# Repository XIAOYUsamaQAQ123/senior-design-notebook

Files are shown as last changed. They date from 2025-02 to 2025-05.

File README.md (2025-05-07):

# Senior Design Notebook

This repository serves as a **digital lab notebook** for Liangcheng's Senior Design project.

## 📂 Structure
- **docs/** → Project documentation
- **experiments/** → Experimental results.
- **src/** → Source code for the project.
- **hardware/** → PCB designs, schematics, and CAD files.
- **reports/** → Proposal, presentation, and final reports.

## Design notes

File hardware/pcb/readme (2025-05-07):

# PCB Designs

This folder contains all the PCB design files used throughout our project. 
It includes schematics, layout files, and fabrication outputs for each board revision.

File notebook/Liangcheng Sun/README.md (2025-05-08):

# Liangcheng Sun’s Worklog

Here is Liangcheng Sun’s worklog.

---
- [**2025-02-12 – Project design & proposal**] 
  I am drawing the full block diagram for our system and then writing up the project proposal so we have a clear plan.
  [Block Diagram](./block_diagram.pdf)
  [PCB Schematic](./main_control_board_schematic.pdf)
  [PCB Design](./main_control_board.pdf)

- [**2025-02-21 – Hardware components ordered online**]
  Based on our design, I went online to order all the needed parts, and I made sure each piece matches our specs.
  Order

- [**2025-02-25 – PCB design kickoff**] 
  After a quick study of PCB layout rules, I began designing our board, placing components and routing tracks step by step.

- [**2025-03-02 – OLED troubleshooting on breadboard**]  
  I built the main circuit on a breadboard, but the OLED display stayed blank—so I measured every pin voltage on both the ESP32 and the OLED, and all readings looked normal.
  OLED Screen:
  ESP32 Wroom 32:

- [**2025-03-06 – Swapped ESP32 for ATmega328**]  
  To isolate the issue, I replaced the ESP32 with an ATmega328, but despite the swap, the screen still would not turn on.
  Arduino nano board ATmega328:

- [**2025-03-12 – Demo & TA feedback (moved to ML training)**]
  During our breadboard demo, we showed partial functions and explained the OLED issue to TA Maanas and Professor—then they suggested skipping the OLED for now and focusing on ML model training and the camera interface.

- [**2025-03-23 – OLED still failing after hardware swap**]
  Even after replacing all hardware modules and checking connections again, the OLED remains unresponsive, so I need another plan.

- [**2025-04-15 – Raspberry Pi camera setup & capture via SSH**] 
  I successfully set up the Raspberry Pi camera, and now I can control it from my laptop via SSH to capture images automatically.
  Raspberry Pi 4: 
  Camera Module:

- [**2025-04-23 – Redesign: ATmega328 + remote display + nRF24L01**]
  We redesigned our system: kept the ATmega328, removed the OLED in favor of a screen on a remote device, and added two nRF24L01 modules so the Pi and ATmega can talk wirelessly; I then laid out and ordered a new PCB.
  [New Block Diagram](./final_block_diagram.pdf)
  [New PCB Schematic](./alert_system_board_schematic.pdf)
  [New PCB Design](./alert_system_board.pdf)
  nRF24L01:

- [**2025-04-26 – Swapped Pi camera for webcam**(./2025-04-26.md)  
  To improve reliability, I replaced the Pi camera module with a standard USB webcam that works smoothly.

- [**2025-04-27 – nRF24L01 issues → fallback to USB cable**]
  After facing unreliable links with the nRF24L01 modules, I decided to use a USB cable to connect the Pi and ATmega directly, which is more stable.

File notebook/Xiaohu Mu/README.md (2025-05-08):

# Xiaohu Worklog 
- [Xiaohu Worklog](#Xiaohu-worklog)
- [2025-02-17-Discussion with Professor Fliflet](##2025-02-17-Discussion-with-Professor-Fliflet)
- [2025-02-27-PCB Update](##2025-02-27-PCB-Update)
- [2025-03-03-Initial Design on Breadboard](#2025-03-03-Initial-Design-on-Breadboard)
- [2025-03-17-Working on the YOLOV5 model](#2025-03-17-Working-on-the-YOLOV5-model)
- [2025-04-21-Working on the UI and ssh connection to laptop](#2025-04-21-Working-on-the-UI-and-ssh-connection-to-laptop)
- [2025-04-27-Trasplanting the model from laptop to Raspberry Pi](#2025-04-27-Trasplanting-the-model-from-laptop-to-Raspberry-Pi)
---
## 2025-02-17-Discussion with Professor Fliflet
During the proposal review, Professor Fliflet provided suggestions for implementing the ideas we outlined. We decided to use the YOLOv5 model as our baseline to recognize and classify tools across various categories. We plan to train the model on our laptop before deploying it to a Raspberry Pi. Additionally, we will use an LCD screen to display item statuses on both the bench and in the drawer.
## 2025-02-27-PCB Update
We came up with an initial PCB design that includes the STM32 microcontroller, an LED, and a buzzer.
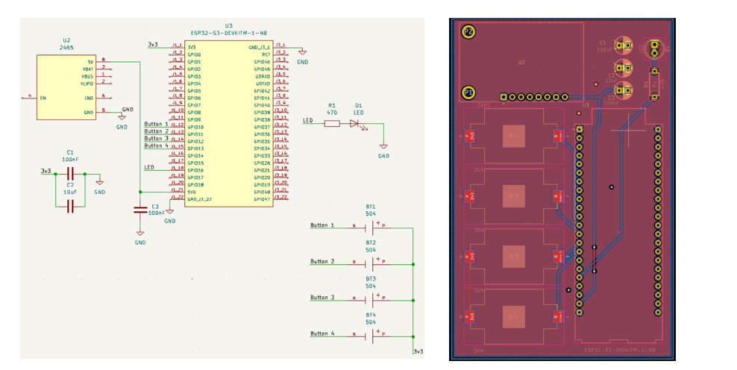
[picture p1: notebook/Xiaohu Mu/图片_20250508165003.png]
PCB Initial Design

## 2025-03-03-Initial Design on Breadboard
For our breadboard demonstration, we attempted to connect the LCD screen to the STM32 microcontroller, but it did not function as expected. Additionally, the STM32 failed to transmit data reliably to the laptop.
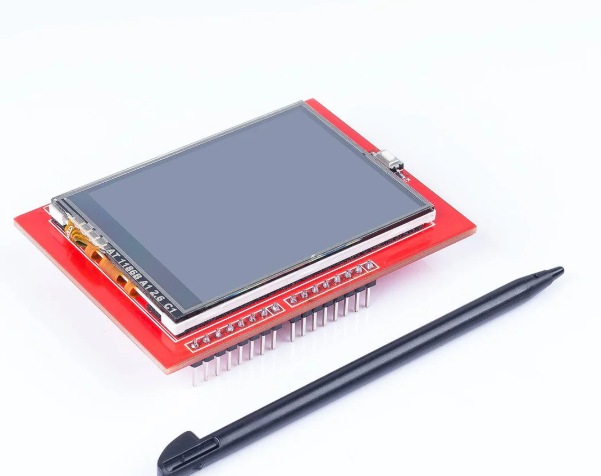
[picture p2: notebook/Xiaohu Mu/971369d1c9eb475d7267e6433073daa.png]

## 2025-03-17-Working on the YOLOV5 model
I trained a YOLOv5 model to recognize tools across different categories, using a dataset from [Kaggle](https://www.kaggle.com/datasets/vdeshmukh18/segmented-screw-driver-dataset). Initially, I trained the model on approximately 200 images per category. However, when I use the model to detect screwdrivers, it takes a long time to recognize the item.
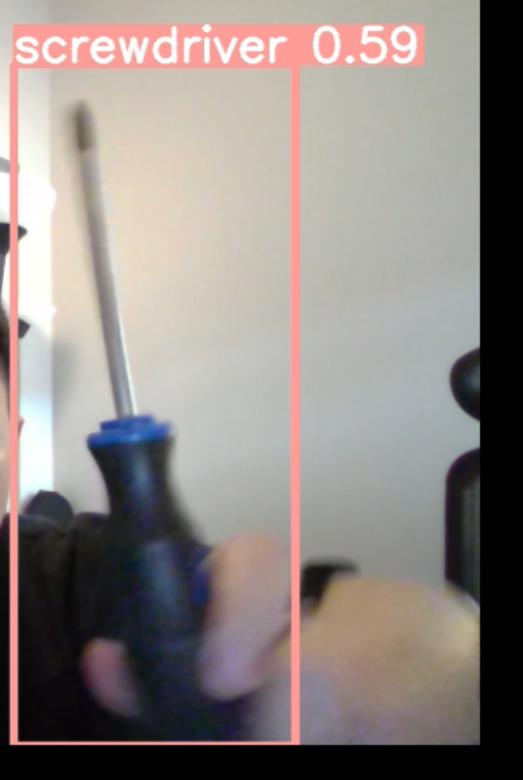
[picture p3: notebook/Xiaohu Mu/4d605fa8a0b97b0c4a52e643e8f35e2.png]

## 2025-04-21-Working on the UI and ssh connection to laptop
I abandoned the LCD screen because it did not work reliably. Instead, I developed UI code that allows users to monitor item status from any device on the same Wi-Fi network as the Raspberry Pi. I also replaced the STM32 with an Arduino Nano for better compatibility.
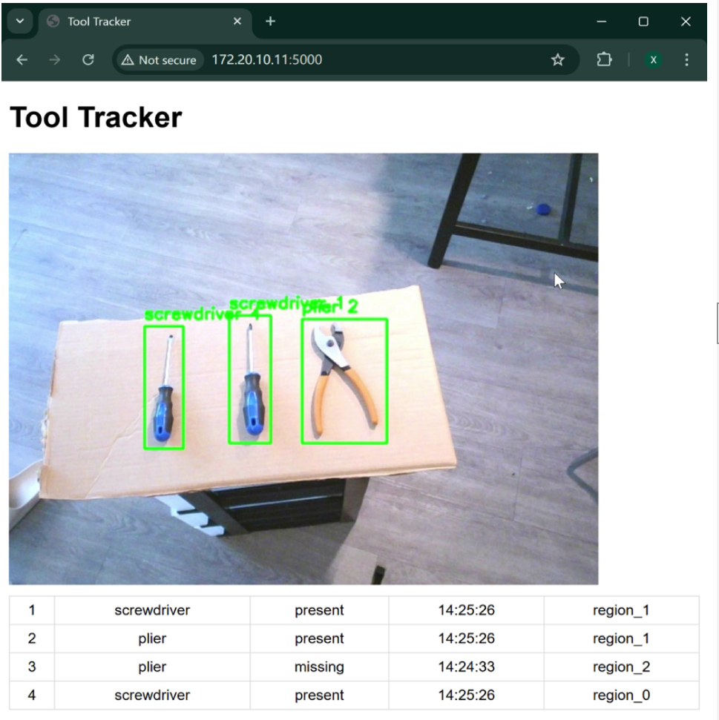
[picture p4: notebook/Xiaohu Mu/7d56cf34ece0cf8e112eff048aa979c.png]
UI Interface

## 2025-04-27-Trasplanting the model from laptop to Raspberry Pi
I further improved the model’s accuracy, allowing it to recognize items from at least three categories. Then I transplanted the entire system to the Raspberry Pi and connected the Arduino Nano to it.

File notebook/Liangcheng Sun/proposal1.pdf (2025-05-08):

# Bench Organizer

## Senior Design Laboratory - Project Proposal

Team #12

Liangcheng Sun, Xiaohu Mu

TA: Agrawal, Maanas Sandeep

February 13, 2025

Table of Contents

### 1. Introduction

1.1. Problem Statement
1.2. Solution
1.3. Visual Aid
1.4. High-Level Requirements

### 2. Design and Requirements

2.1. Block Diagram
2.2. Subsystem Descriptions
2.3. Tolerance/Risk Analysis

### 3. Ethics and Safety

3.1. Ethics
3.2. Safety

### 4. References

### 1. Introduction

### 1.1 Problem Statement

In shared workspaces such as maker spaces, engineering labs, and mechanical workshops, tools are frequently misplaced or missed due to human error. Users often forget to return tools to their designated locations after use. This typically leads to inefficiencies, wasted time, and workflow disruptions. Existing solutions, such as manual sign-out sheets, RFID-based systems, and barcode scanning, require extra effort from users.

A more advanced and convenient solution is needed to track shared tools in real-time without requiring users to scan tags or log tool usage manually. The system should be capable of identifying tools, monitoring their movement, and ensuring they are returned to their proper storage locations. By minimizing loss and disorganization without adding additional inconvenience to the user experience, this solution can significantly improve efficiency and resource management in shared workspaces.

### 1.2 Solution

We propose a computer vision-based Bench Organizer that utilizes a camera to monitor a tool rack in real time, reduce tool misplacement, and improve efficiency in shared workspaces. The system employs OpenCV-based object detection models to detect and recognize tools and allow users to manually record a reference frame that captures the correct tool arrangement. By comparing the current frame with the recorded reference, users can quickly identify missing tools. Additionally, the system performs automatic checks at pre-set intervals to ensure tool availability and logs tool usage history, notifying users when a tool has been missing for an extended period.

To enhance user interaction and reliability, the system provides real-time alerts via LED indicators when tools are missing. It features a Bluetooth-connected camera module (Raspberry Pi Camera + Bluetooth Adapter) that operates separately from the processing unit, allowing flexible placement. Instead of a touchscreen, it uses a standard display screen with four physical buttons for control, ensuring simplicity and durability. This automated, low-maintenance solution improves organization and minimizes time wasted in shared work environments. In addition, cameras are also set in or near drawers to monitor the items inside drawers

### 1.3 Visual Aid

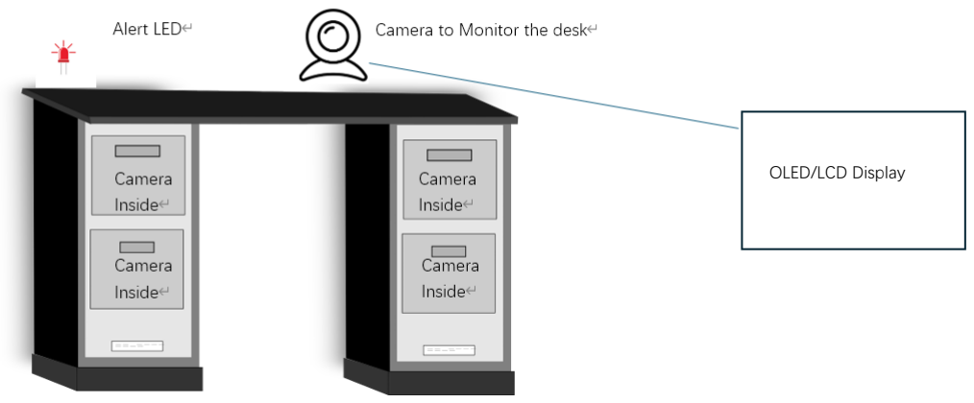
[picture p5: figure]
OLED/LCD Display

Figure 1: Visual Representation of the Bench Organizer

### 1.4 High-Level Requirements

- Accuracy and Responsiveness: The most important success indicator of our project is the accuracy of recognition and system responsiveness. Using a pre-trained machine learning model, we expect the system to recognize 90% of the items within the model’s category. Additionally, by utilizing the Bluetooth module, we anticipate that the recognition process will take less than two seconds.
- Robustness: In real-world scenarios, the system may be affected by varying lighting conditions. In this case, we must ensure that the system is robust enough to function reliably without being impacted by these variations. Additionally, the system should be able to differentiate whether a user is taking or placing an item based on the movement of their hands.
- Extended Functionality: We also expect that when an uncategorized item appears in the camera's view, users will receive a notification and be able to scan it into the system. The next time the item is detected, the system should be able to recognize it.

### 2. Design and Requirements

### 2.1 Block Diagram

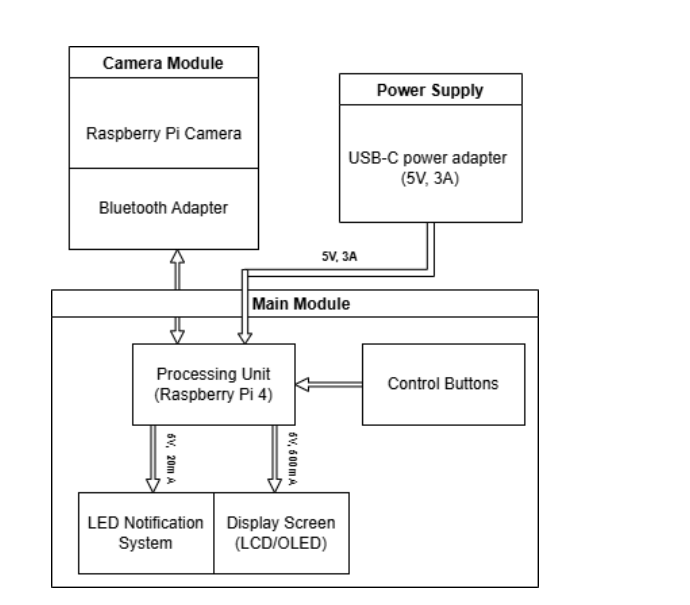
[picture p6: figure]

Figure 2 Block Diagram

### 2.2 Subsystem Description

Camera Subsystem

Functionality:

The Camera Subsystem has one primary camera to monitor the user’s activity on the tool rack to track the tool usage. Additionally, multiple cameras are integrated to monitor the changes in items stored within drawers to capture the additions or removals in real time.

Contribution:

This subsystem captures the activity of the tool rack and drawer contents and transmits the images/videos to the processing unit via Bluetooth. By continuously monitoring tool interactions, it enables the system to detect missing or misplaced items. Furthermore, the camera subsystem also allows the system to recognize new tools added by users

Interface:

Inputs:

1. Visual Data (Images/Videos)
2. Command from the Processing Unit
3. Power source

Outputs:

1. Videos/Image Information transmitted to the processing unit via Bluetooth.

Processing Subsystem

Functionality:

The processing subsystem is powered by Raspberry Pi 4, which serves as the central computing unit. It runs the pre-trained classification model using OpenCV that allows real-time recognition and tracking of tools. The model could recognize the items on the desk, detect missing tools or misplaced tools, and determine the appropriate drawer for storing newly introduced objects. In addition, it also manages the user interactions with the display and button inputs

Contribution:

This subsystem is responsible for analyzing visual data received from the Camera Subsystem, executing object detection algorithms, and making decisions based on tool presence and location. It also reduces tool misplacement and enhances workspace efficiency. Furthermore, it facilitates user feedback mechanisms, such as triggering LED indicators, updating the display, and logging tool usage history.

Interface:

Inputs:

1. Image and Video Data
2. Control Signal from the button
3. 5V/3A Power supply

Outputs:

1. Tool Status (missing, misplaced, newly added) updated to the Display
2. Control signal for LED indicators
3. Logged Data for usage history

User Interface Subsystem

Functionality:

This subsystem provides a visual and interactive platform for users to monitor and manage tool organization. It includes an OLED display to present real-time item information, including tool status, missing or misplaced items, and storage guidance. Users can interact with the system through physical buttons to look for the items or log in a new item to the drawer. Additionally, an LED indicator serves as a visual alert to notify users when a tool is missing or misplaced.

Contribution:

This subsystem enhances user experience and accessibility by offering clear visual feedback and intuitive controls. By displaying real-time tool status and guiding proper organization, it helps reduce misplacement and ensures efficient workspace management. The LED indicator provides an immediate alert. The button interface ensures reliable operation without requiring a touchscreen.

Interface:

Inputs:

1. Tool Status Signal from the Processing Unit
2. Button Presses by User
3. Power Supply

Outputs:

1. OLED Display Updates
2. LED Indicator Alerts

Power Subsystem

- The Raspberry Pi 4 is powered via a 5V, 3A USB-C power adapter or battery pack.
- The Bluetooth Camera Module is powered by a 3.7V Li-ion battery with a 5V Boost Converter.
- The Display and LED Notification System are powered through the Raspberry Pi GPIO (5V/3.3V).

### 2.3 Tolerance/Risk Analysis

During the detection process, several factors can impact accuracy, including camera resolution, lighting conditions, and the angle of view. Variations in these parameters may lead to detection failures. To achieve 90% accuracy, as specified in our high-level requirements, we must limit the angle of view tolerance to ±15° and restrict light variance to within ±20% to ensure consistent recognition performance.

Another critical factor to consider is processing time, as delays in response could affect usability. To meet the 2-second response time requirement, Bluetooth transmission delay must be kept below 500 ms, and button response time should not exceed 200 ms to ensure smooth and timely interactions. By maintaining these constraints, the system can provide reliable, real-time tool tracking and user feedback.

3. Ethics and Safety.

### 3.1 Ethics

The project aligns with the IEEE Code of Ethics and ensures that its development and usage promote fairness.

One key ethical consideration is user privacy. The system only captures and processes the images of tools and workspace interaction. It should avoid any forms of identification of the user’s personal information. All captured data is strictly used and only used in the bench organizer system. Additionally, transparency is maintained by allowing users to manually update tool information.

### 3.2 Safety

In regards to safety, the system is designed to operate safely in a workshop or lab environment to minimize risks to users and workspace equipment. The system runs on low-voltage power sources to prevent electrical hazards. The battery pack will be a certified lithium-ion battery with proper overcharge and short-circuit protection to ensure safe and stable operation.

References

1. IEEE, “IEEE Code of Ethics.” [Online]. Available: https://www.ieee.org/about/corporate/governance/p7-8.html. [Accessed: Feb. 13, 2025]

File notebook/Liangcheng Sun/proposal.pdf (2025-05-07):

# Bench Organizer

## Senior Design Laboratory - Project Proposal

Team #12

Liangcheng Sun, Xiaohu Mu

TA: Agrawal, Maanas Sandeep

February 13, 2025

Table of Contents

### 1. Introduction

1.1. Problem Statement
1.2. Solution
1.3. Visual Aid
1.4. High-Level Requirements

### 2. Design and Requirements

2.1. Block Diagram
2.2. Subsystem Descriptions
2.3. Tolerance/Risk Analysis

### 3. Cost and Schedule

3.1. Cost Analysis
3.2. Schedule

### 4. Ethics and Safety

4.1. Ethics
4.2. Safety

### 5. References

### 1. Introduction

### 1.1 Problem Statement

In shared workspaces such as maker spaces, engineering labs, and mechanical workshops, tools are frequently misplaced or missed due to human error. Users often forget to return tools to their designated locations after use. This typically leads to inefficiencies, wasted time, and workflow disruptions. Existing solutions, such as manual sign-out sheets, RFID-based systems, and barcode scanning, require extra effort from users. A more advanced and convenient solution is needed to track shared tools in real-time

without requiring users to scan tags or log tool usage manually. The system should be capable of identifying tools, monitoring their movement, and ensuring they are returned to their proper storage locations. By minimizing loss and disorganization without adding additional inconvenience to the user experience, this solution can significantly improve efficiency and resource management in shared workspaces. 1.2 Solution

We propose a computer vision-based Bench Organizer that utilizes a camera to monitor a tool rack in real time, reduce tool misplacement, and improve efficiency in shared workspaces. The system employs OpenCV-based object detection models to detect and recognize tools and allow users to manually record a reference frame that captures the correct tool arrangement. By comparing the current frame with the recorded reference, users can quickly identify missing tools. Additionally, the system performs automatic checks at pre-set intervals to ensure tool availability and logs tool usage history, notifying users when a tool has been missing for an extended period. To enhance user interaction and reliability, the system provides real-time alerts via

LED indicators when tools are missing. It features a Bluetooth-connected camera module (Raspberry Pi Camera + Bluetooth Adapter) that operates separately from the processing unit, allowing flexible placement. Instead of a touchscreen, it uses a standard display screen with four physical buttons for control, ensuring simplicity and durability. This automated, low-maintenance solution improves organization and minimizes time wasted in shared work environments. In addition, cameras are also set in or near drawers to monitor the items inside drawers

### 1.3 Visual Aid

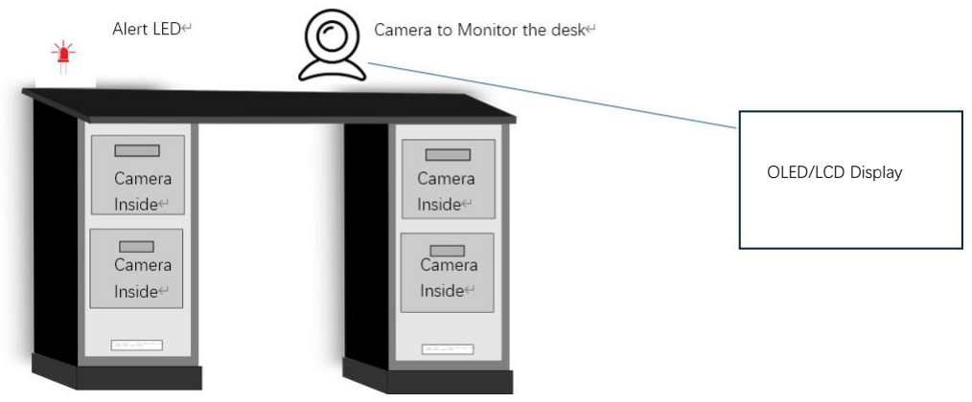
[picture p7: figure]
OLED/LCD Display

Figure 1: Visual Representation of the Bench Organizer

As shown above, each drawer contains a camera to monitor the activity of the item in it. The camera on the bench is used to monitor the user’s activity on the bench. The microcontroller records the item information based on the camera information in

the drawer. It also update the status (misplaced, using, lost) of items based on the camera on the bench. The OLED/LCD is used to display each item’s status. The alert LED is used to inform when items are missing or misplaced. 1.4 High-Level Requirements

- Accuracy and Responsiveness: The most important success indicator of our project is the accuracy of recognition and system responsiveness. Using a pre-trained machine learning model, we expect the system to recognize 90% of the items within the model’s category. Additionally, by utilizing the Bluetooth module, we anticipate that the recognition process will take less than two seconds. Robustness: In real-world scenarios, the system may be affected by varying

lighting conditions. In this case, we must ensure that the system is robust enough to function reliably without being impacted by these variations. Additionally, the system should be able to differentiate whether a user is

taking or placing an item based on the movement of their hands. Extended Functionality: We also expect that when an uncategorized item

appears in the camera's view, users will receive a notification and be able to scan it into the system. The next time the item is detected, the system should be able to recognize it. 2. Design and Requirements

### 2.1 Block Diagram

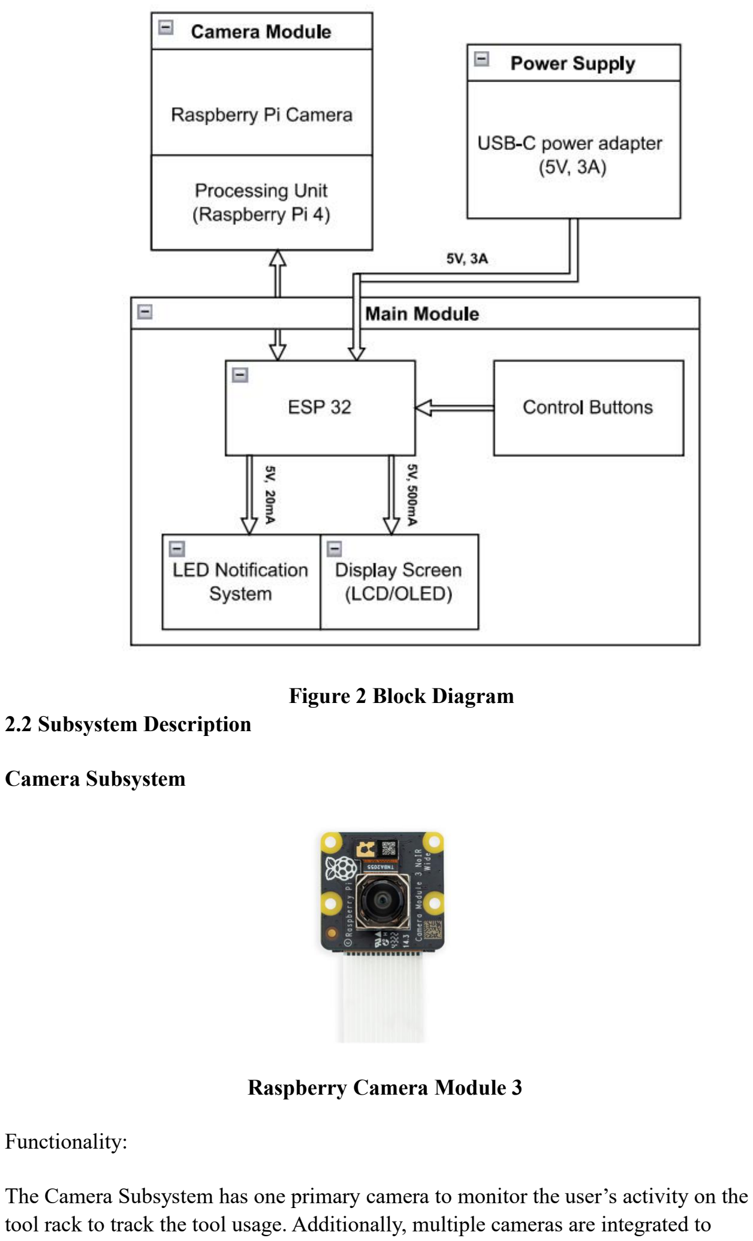
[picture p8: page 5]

Figure 2 Block Diagram

### 2.2 Subsystem Description

Camera Subsystem

Raspberry Camera Module 3

Functionality:

The Camera Subsystem has one primary camera to monitor the user’s activity on the tool rack to track the tool usage. Additionally, multiple cameras are integrated to monitor the changes in items stored within drawers to capture additions or removals in real time. Contribution:

This subsystem captures the activity of the tool rack and drawer contents and transmits the images/videos to the processing unit via Bluetooth. By continuously monitoring tool interactions, it enables the system to detect missing or misplaced items. Furthermore, the camera subsystem also allows the system to recognize new tools added by users

Interface:

Inputs:

1. Visual Data (Images/Videos)
2. Command from the Processing Unit
3. Power source

Outputs:

1. Videos/Image Information transmitted to the processing unit via WIFI. Requirement 1:

The Camera Subsystem must be able to accurately identify the same item under varying angles and lighting conditions. Verification 1:

Test the subsystem by placing the same item in front of the camera at different angles and under different lighting conditions to confirm its ability to correctly identify the item. Requirement 2:

The Camera Subsystem must be able to accurately distinguish between different items to prevent confusion and errors. Verification 2:

Test the subsystem by placing similar items in front of the camera and verify whether it correctly identifies and differentiates each item. Processing Subsystem

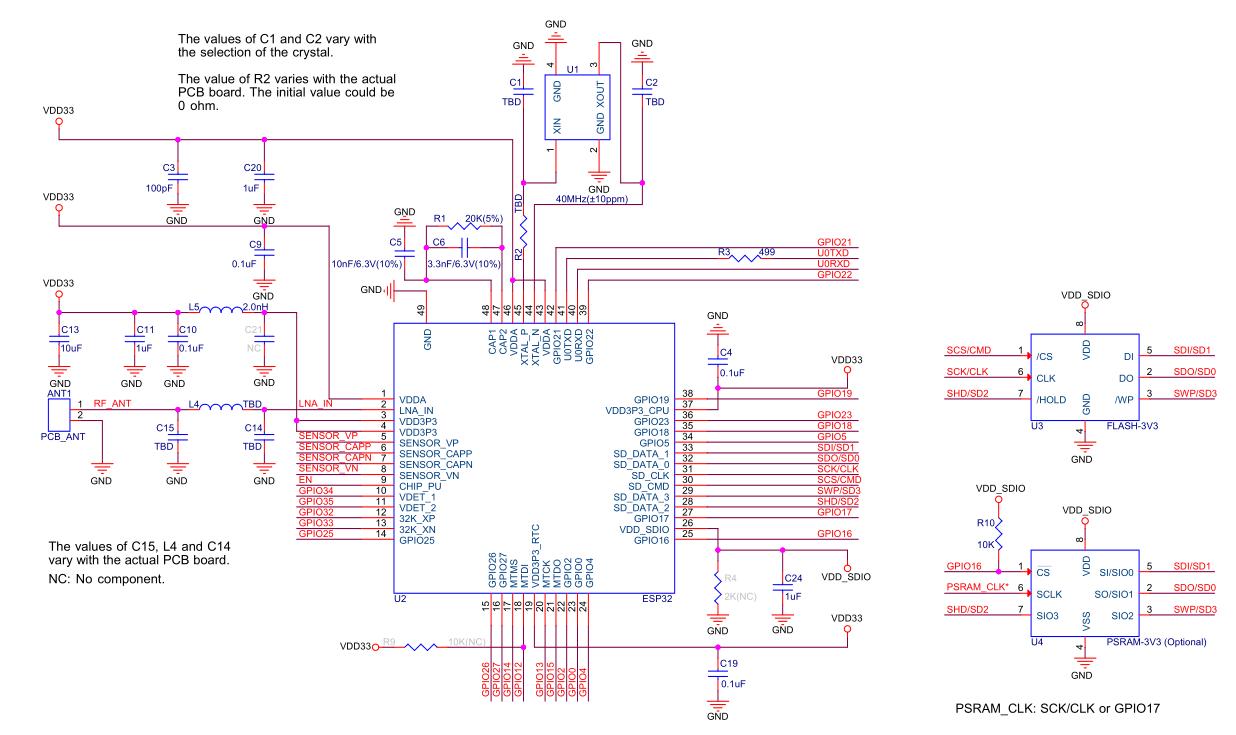
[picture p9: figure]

ESP 32 Reference Schematic

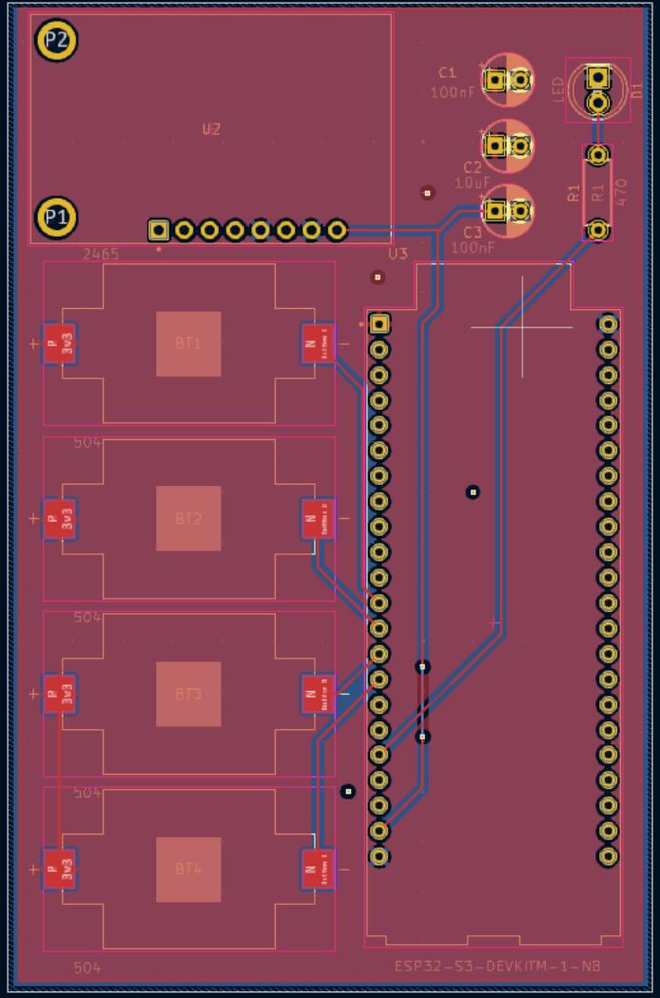
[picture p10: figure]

Main Control Board

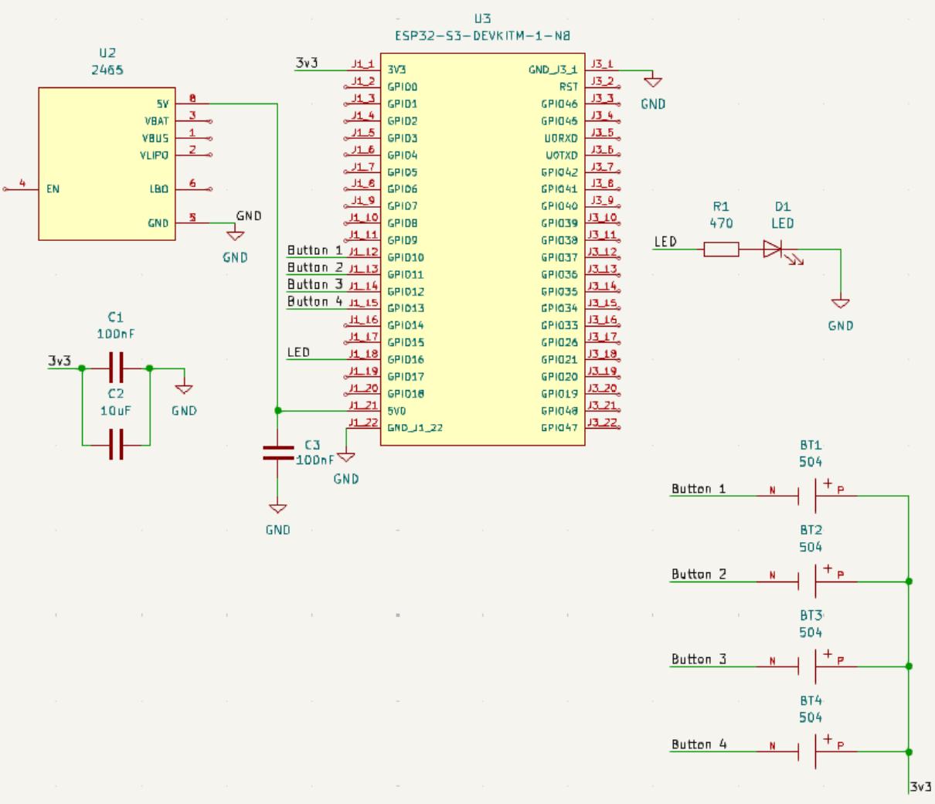
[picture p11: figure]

Main Control Board Schematic

Functionality:

The processing subsystem is powered by a microcontroller ESP 32, which serves as the central computing unit. It runs the pre-trained classification model using OpenCV which allows real-time recognition and tracking of tools. The model could recognize the items on the desk, detect missing tools or misplaced tools, and determine the appropriate drawer for storing newly introduced objects. In addition, it also manages the user interactions with the display and button inputs

Contribution:

This subsystem is responsible for analyzing visual data received from the Camera Subsystem, executing object detection algorithms, and making decisions based on tool presence and location. It also reduces tool misplacement and enhances workspace efficiency. Furthermore, it facilitates user feedback mechanisms, such as triggering LED indicators, updating the display, and logging tool usage history. Interface:

Inputs:

1. Image and Video Data
2. Control Signal from the button
3. 5V/3A Power supply

Outputs:

1. Tool Status (missing, misplaced, newly added) updated to the Display
2. Control signal for LED indicators
3. Logged Data for usage history

Requirement 1:
The processing subsystem must be capable of receiving and transmitting data to and from other subsystems, including the Camera Subsystem and the User Interface Subsystem. Verification 1:

Print the data or image received from the subsystems to verify that they match the expected results. Requirement 2:

The processing subsystem must be able to update the status of each item when its status changes within the camera's view. The subsystem should be able to make the status change in 5 seconds. Verification 2:

Manually change the status of specific items on the bench or in the drawer (e.g., remove an item from the bench or place an item in the drawer) and verify whether the

system correctly updates the item’s status. Requirement 3:

The processing subsystem must be able to log information for any new item introduced to the system. Verification 3:

Place an item that is not already in the system's database and register it. Verify that the item’s information is accurately recorded in the system. User Interface Subsystem

Functionality:

This subsystem provides a visual and interactive platform for users to monitor and manage tool organization. It includes an OLED display to present real-time item information, including tool status, missing or misplaced items, and storage guidance. Users can interact with the system through physical buttons to look for the items or

log in a new item to the drawer. Additionally, an LED indicator serves as a visual alert to notify users when a tool is missing or misplaced. Contribution:

This subsystem enhances user experience and accessibility by offering clear visual feedback and intuitive controls. By displaying real-time tool status and guiding proper organization, it helps reduce misplacement and ensures efficient workspace management. The LED indicator provides an immediate alert. The button interface ensures reliable operation without requiring a touchscreen. Interface:

Inputs:

1. Tool Status Signal from the Processing Unit
2. Button Presses by User
3. Power Supply

Outputs:

1. OLED Display Updates
2. LED Indicator Alerts

Requirement:
The user must be able to locate an item by searching for it in the interface.

Verification:
Place an item in the drawer and verify that its status is correctly updated in the interface, indicating that it is in the drawer. Power Subsystem
- The Raspberry Pi 4 is powered via a 5V, 3A USB-C power adapter or battery pack. • The Bluetooth Camera Module is powered by a 3.7V Li-ion battery with a 5V Boost

Converter. • The Display and LED Notification System are powered through the Raspberry Pi

GPIO (5V/3.3V). 2.3 Tolerance/Risk Analysis

During the detection process, several factors can impact accuracy, including camera resolution, lighting conditions, and the angle of view. Variations in these parameters may lead to detection failures. To achieve 90% accuracy, as specified in our high-level requirements, we must limit the angle of view tolerance to ±15° and restrict light variance to within ±20% to ensure consistent recognition performance. Another critical factor to consider is processing time, as delays in response could

affect usability. To meet the 2-second response time requirement, Bluetooth transmission delay must be kept below 500 ms, and button response time should not exceed 200 ms to ensure smooth and timely interactions. By maintaining these constraints, the system can provide reliable, real-time tool tracking and user feedback. 4. Cost and Schedule

### 4.1 Cost Analysis

Description | Part Number | Unit Price | Quantity | Total Price
Raspberry Pi Processor | PI4-4GB-STR32F-C4-BLK | 119.95 | 1 | 119.95
Raspberry Pi Camera | RSP-CAM-V3-WIDE | 35 | 1 | 35
Drawer Organizer | N/A | 40 | 1 | 40
Camera | NexiGo N60 | 29.99 | 2 | 59.98

Microcontroller | ESP-32 | 15.95 | 1 | 15.95

4.2 Schedule
| Xiaohu Mu | Liangcheng Sun
Week of 3/10 | PCB ordering | Check the PCB design
Week of 3/17 | Train the Model for Item classification and recognition | Write the code for the Item Status system
Week of 3/24 | Continue on train the Model for Item classification and recognition | Continue on write the code for the Item Status system
Week of 3/31 | Test the power | Connect the PCB with other subsystems
Week of 4/7 | Program the Bluetooth | Program on Raspberry processor
Week of 4/14 | Test bugs and functionality for the software | Test bugs and functionality for the hardware and raspberry
Week of 4/21 | Mock demo | Mock demo
Week of 4/28 | Final demo | Final demo
Week of 5/5 | Final Presentation | Final Presentation

### 5. Ethics and Safety

### 5.1 Ethics

The project aligns with the IEEE Code of Ethics and ensures that its development and usage promote fairness. One key ethical consideration is user privacy. The system only captures and processes

the images of tools and workspace interaction. It should avoid any forms of identification of the user’s personal information. All captured data is strictly used and only used in the bench organizer system. Additionally, transparency is maintained by allowing users to update tool information manually. Another key ethical consideration is theft prevention. If an item is taken from the

bench without authorization, the system should be capable of detecting the removal and identifying the individual responsible. This can be achieved through real-time monitoring, facial recognition, or access logs, ensuring accountability and reducing the risk of theft. Additionally, the system should provide alerts or notifications to inform the user or relevant personnel of any unauthorized item removal. 5.2 Safety

In regards to safety, the system is designed to operate safely in a workshop or lab environment to minimize risks to users and workspace equipment. The system runs on low-voltage power sources to prevent electrical hazards. The battery pack will be a certified lithium-ion battery with proper overcharge and short-circuit protection to ensure safe and stable operation.

References

1. IEEE, “IEEE Code of Ethics.” [Online]. Available: https://www.ieee.org/about/corporate/governance/p7-8.html. [Accessed: Feb. 13, 2025]
2. Dwyer, B. (2025, February 4). How to deploy computer vision models to a Raspberry Pi. Roboflow Blog. https://blog.roboflow.com/raspberry-pi-computer-vision/
3. Schematic ChecklistÁ. Schematic Checklist - ESP32 - - ESP Hardware Design Guidelines latest documentation. (n.d.). https://docs.espressif.com/projects/esp-hardware-design-guidelines/en/latest/esp32

/schematic-checklist.html

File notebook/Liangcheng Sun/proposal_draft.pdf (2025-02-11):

# Bench Organizer Proposal

### Liangcheng Sun (ls25), Xiaohu Mu (xiaohum2)

### ECE 445 - Senior Design

## 1 Introduction

### 1.1 Problem and Background

Most desk organizers function only as storage compartments without actively helping users maintain organization or productivity. Small but frequently used items such as pens, keys, and tools are often misplaced, leading to unnecessary time spent searching for them. While digital organization tools exist, they do not integrate well with physical workspaces. A solution is needed that combines digital tracking with physical organization to help users maintain a tidy workspace effortlessly.

### 1.2 Solution with Visual Aid

Our proposed Bench Organizer is a smart desk organizer that uses RFID technology to track items and notify users when they are missing or misplaced. The system will include:

- RFID/NFC tracking to detect item presence in designated slots.
- Visual and audio alerts (LEDs and buzzer) when an item is misplaced or missing.
- Bluetooth notifications to send reminders to a smartphone or computer.
- A custom PCB to integrate and manage all electronic components efficiently.
- (Optional) Wireless charging pad for convenience.

### 1.3 High-Level Requirements

1. The system must detect and track at least 90% of tagged items correctly within 2 cm of the RFID reader.
2. The organizer must provide real-time notifications through LEDs, buzzer alerts, or Bluetooth within 1 second of detecting a missing item.
3. The system should function under normal indoor lighting conditions and work effectively on a standard desk setup.

## 2 Design and Requirements

### 2.1 Block Diagram

The Bench Organizer consists of three main subsystems:

- Item Detection (RFID/NFC Reader): Reads RFID-tagged items and checks their presence.
- Notification (LED, Buzzer, Bluetooth): Alerts the user when items are missing.
- Custom PCB (Power Management
Microcontroller): Ensures proper power distribution and communication between components.

### 2.2 Subsystem Descriptions

Item Detection Subsystem:

- Technology: RFID/NFC tracking.
- Components: PN532 RFID Reader, NFC Tags.
- Functionality: Reads item tags, verifies placement, and signals the notification subsystem.

Notification Subsystem:

- Technology: LED indicators, buzzer, Bluetooth module (HC-05).
- Functionality: Alerts users when an item is missing via LEDs, sound, and Bluetooth notifications.

Custom PCB Subsystem:

- Technology: Microcontroller (Arduino or ESP32), voltage regulators.
- Functionality: Integrates all components, manages power distribution and signal processing.

### 2.3 Subsystem Requirements

- RFID detection must work for items within 2 cm of the reader.
- Alerts (LED, buzzer, Bluetooth) must activate within 1 second of detecting a missing item.
- Power consumption should not exceed 500mA at 5V to ensure efficiency.

### 2.4 Risk Analysis

The biggest challenge is ensuring RFID accuracy and minimizing false negatives (when an item is present but not detected).

- Potential risks: RFID interference, range limitations, power inefficiencies.
- Mitigation strategies: Optimizing antenna placement, software filtering, power management.

## 3 Ethics and Safety

### 3.1 Ethical Considerations

Our project follows IEEE/ACM ethical guidelines, ensuring user privacy, safety, and accessibility. Key considerations include:

- Ensuring data privacy: The system does not store or transmit sensitive user information.
- Reducing electronic waste: Designing an energy-efficient PCB to minimize power consumption.

### 3.2 Safety Considerations

- Electrical Safety: Low voltage operation (5V), circuit insulation.
- Mechanical Safety: Enclosures to prevent accidental short circuits.
- Lab Safety: ESD protection during PCB prototyping.
- User Safety: RFID operates within standard consumer device limits, ensuring no harmful radiation exposure.

## 4 Citations and References

All references are formatted according to IEEE citation guidelines.

1.

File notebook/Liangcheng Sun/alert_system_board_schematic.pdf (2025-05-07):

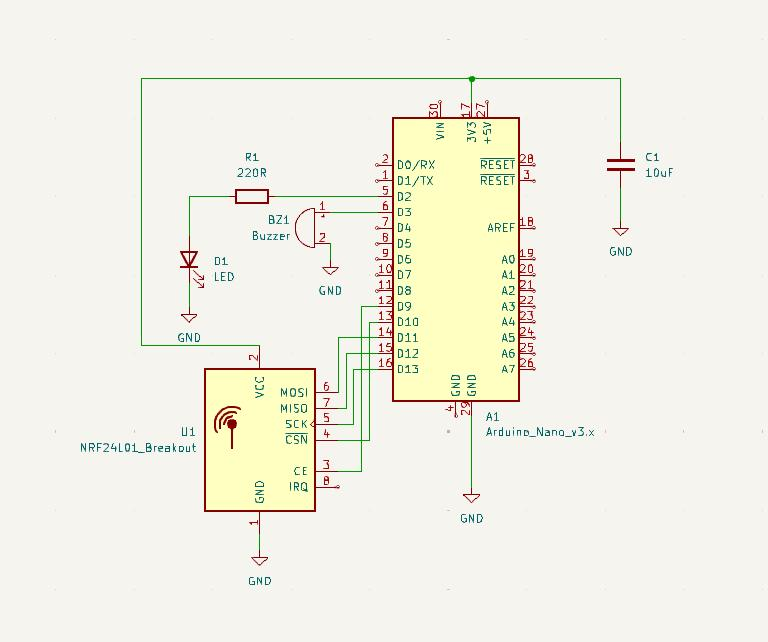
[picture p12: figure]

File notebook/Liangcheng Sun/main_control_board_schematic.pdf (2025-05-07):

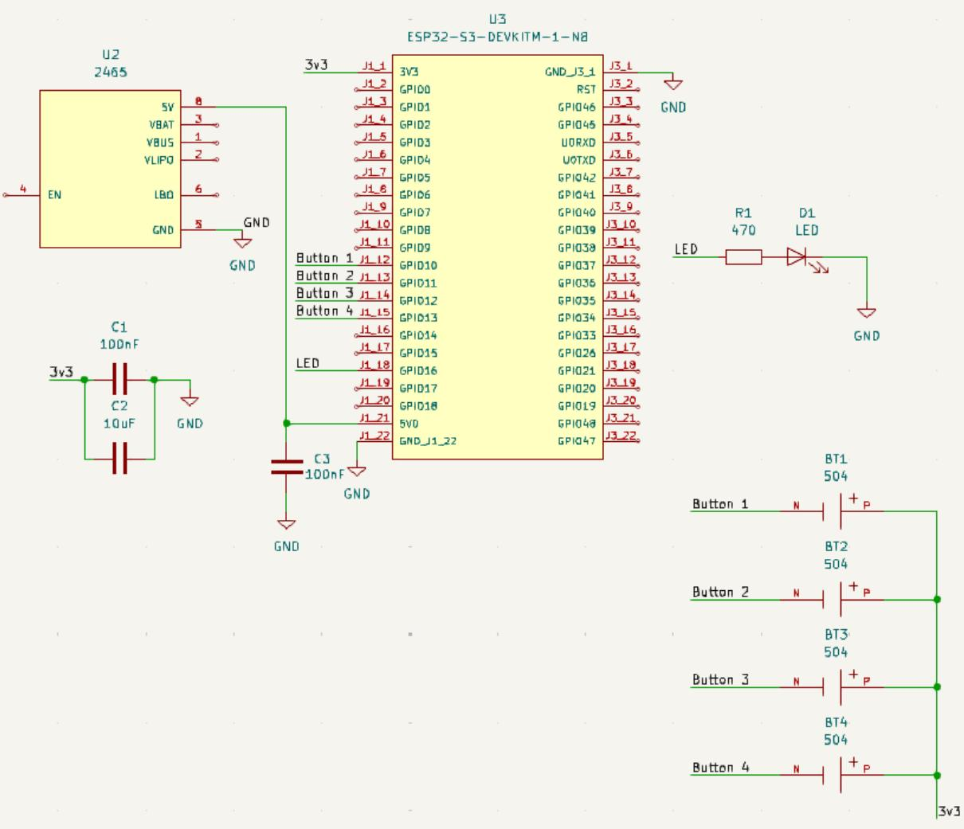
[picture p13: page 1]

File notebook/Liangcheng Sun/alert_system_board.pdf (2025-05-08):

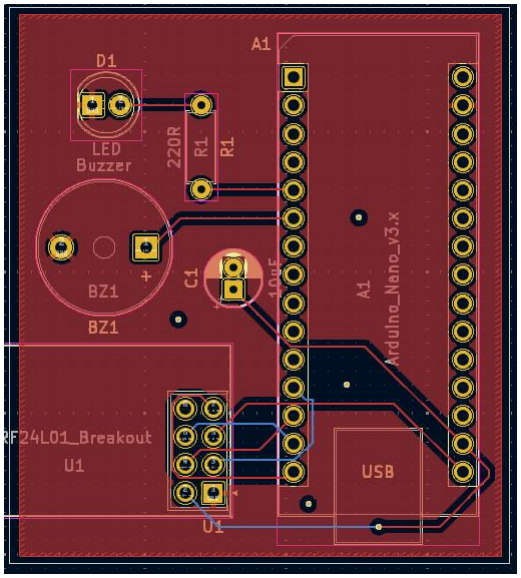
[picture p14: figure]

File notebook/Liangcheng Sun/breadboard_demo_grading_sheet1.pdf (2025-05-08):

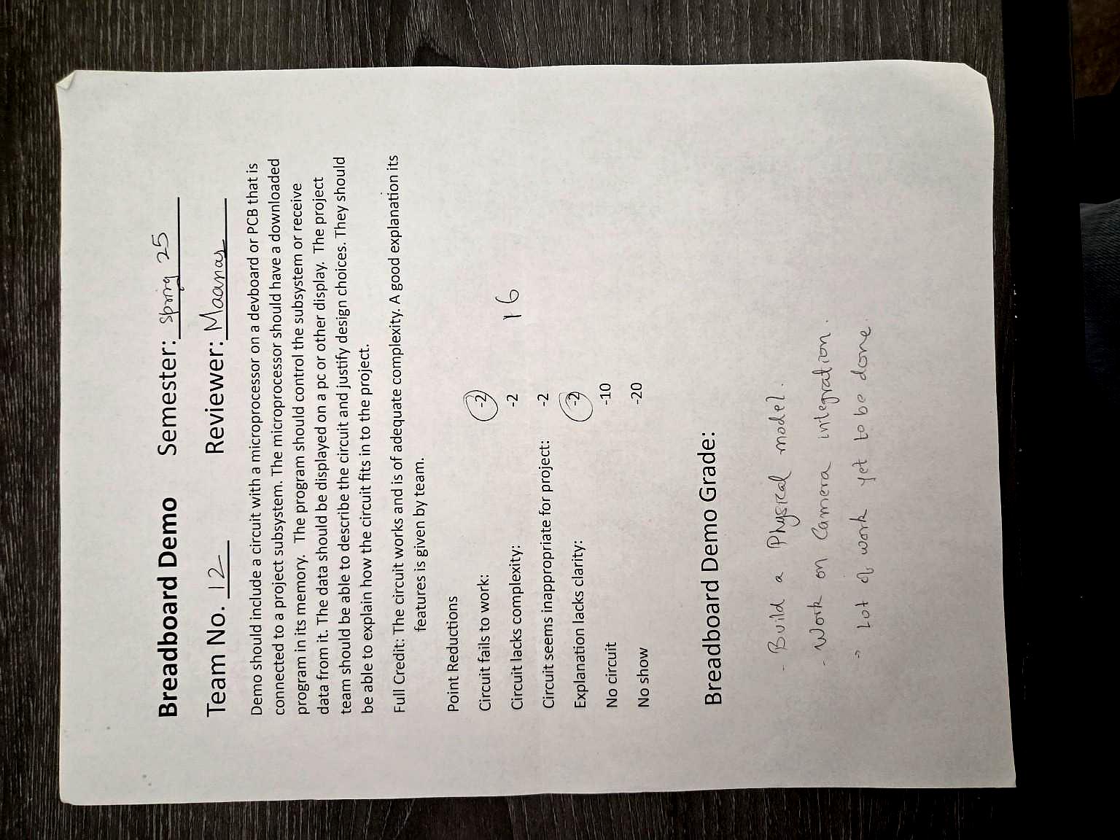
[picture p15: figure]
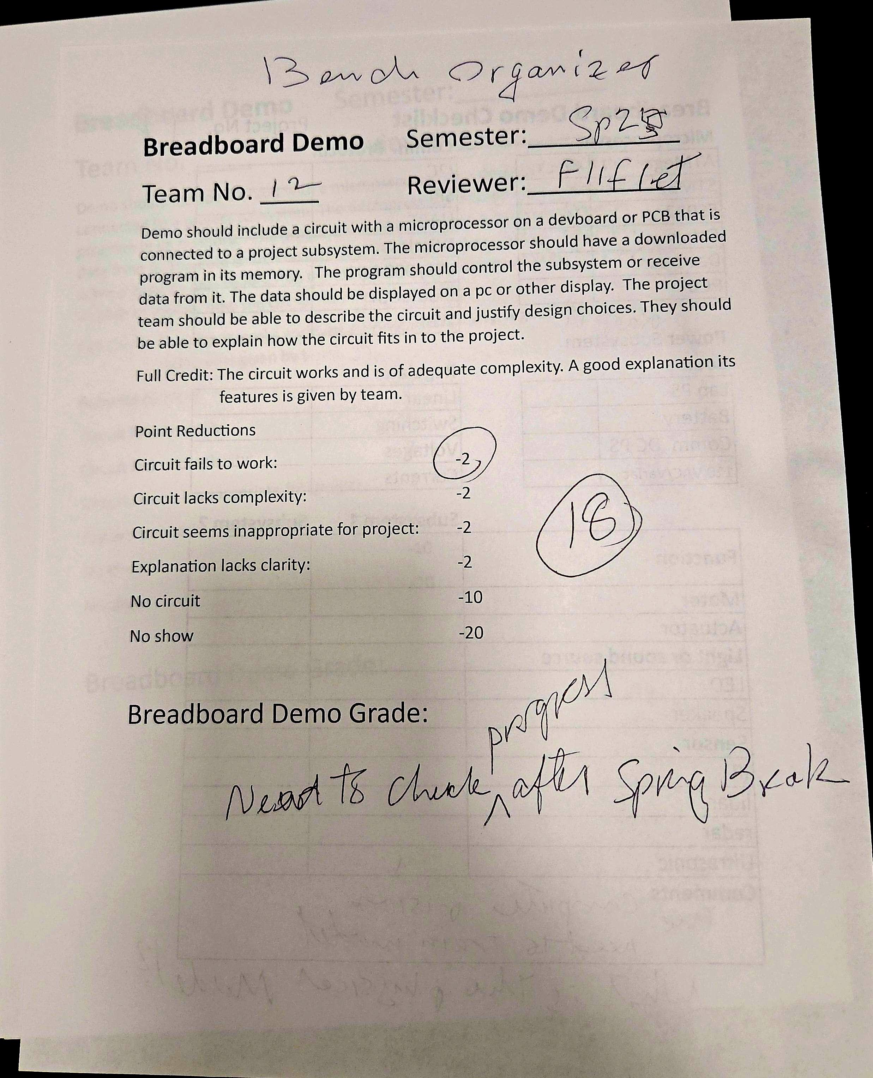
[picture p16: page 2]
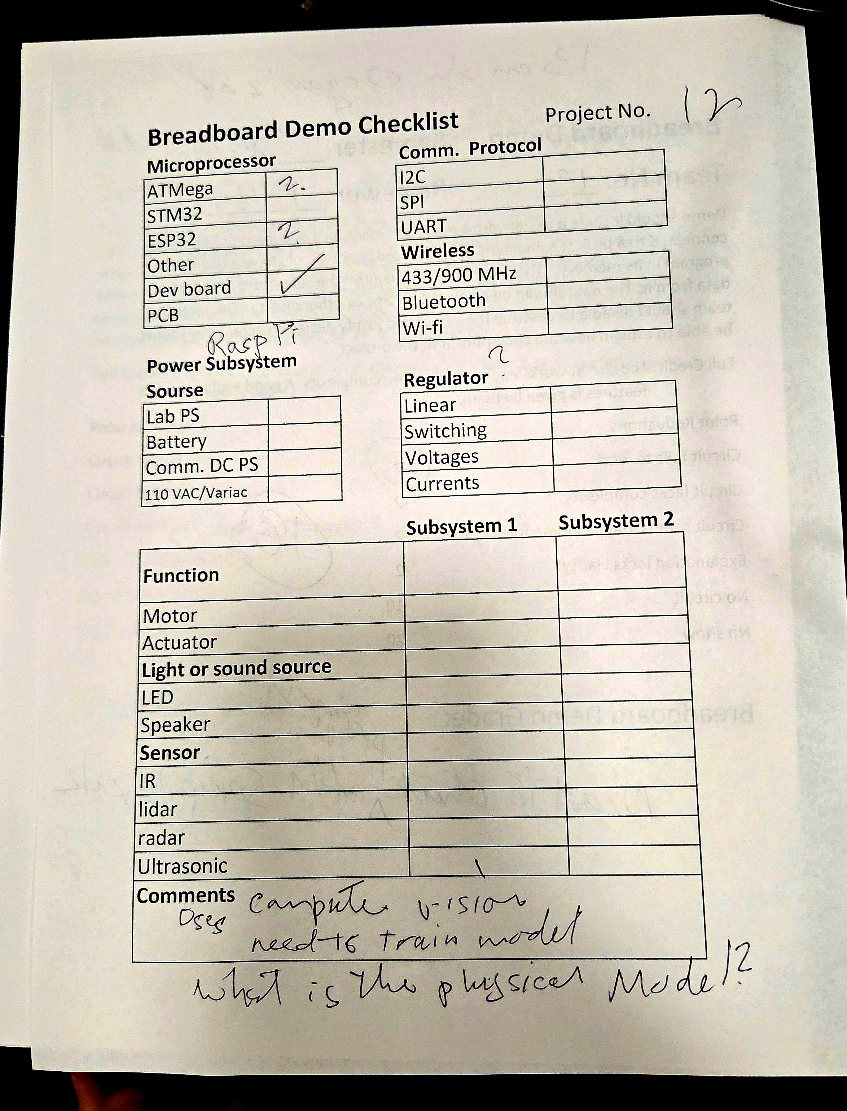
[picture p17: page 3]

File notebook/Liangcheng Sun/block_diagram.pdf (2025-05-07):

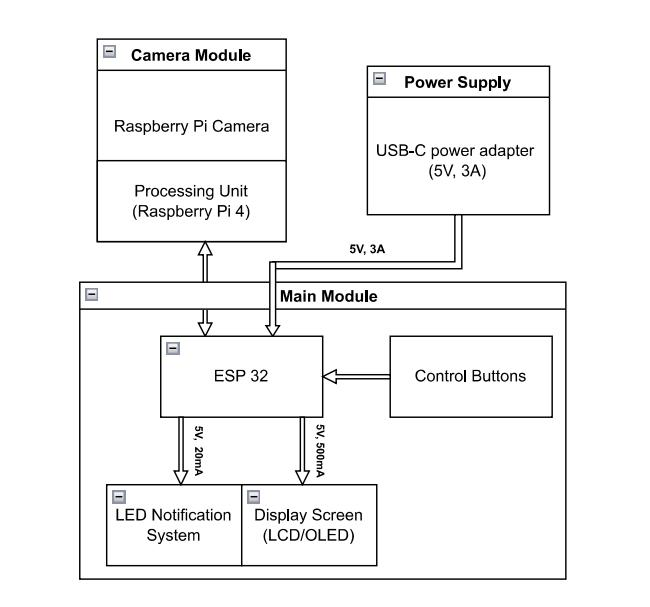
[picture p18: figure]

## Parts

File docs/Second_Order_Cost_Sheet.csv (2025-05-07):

Component | Quantity | Unit Price ($) | Total ($)
20W USB-C Power Adapter | 1 | 14 | 14
USB Webcams | 2 | 15 | 30
Arduino Nano Board ATmega328P 5V 16MHz | 4 | 5 | 20

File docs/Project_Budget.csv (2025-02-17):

 | Component | Estimated Cost (USD)
0 | Raspberry Pi 4 (Processing Unit) | 55
1 | Raspberry Pi Camera Module | 30
2 | Bluetooth Adapter (for Camera) | 10
3 | LCD Display (OLED/Standard) | 20
4 | Physical Buttons (4x) | 8
5 | LED Notification System | 5
6 | Power Supply (USB-C Adapter, 5V 3A) | 15
7 | Battery Pack for Camera (3.7V Li-ion + Boost Converter) | 20
8 | Wiring & Connectors | 10
9 | Miscellaneous (PCB, Casing, Fasteners) | 25
10 | Total Estimated Cost | 198

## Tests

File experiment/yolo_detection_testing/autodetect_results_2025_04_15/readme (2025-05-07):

Here is Raspberry pi camera module initialization testing record.

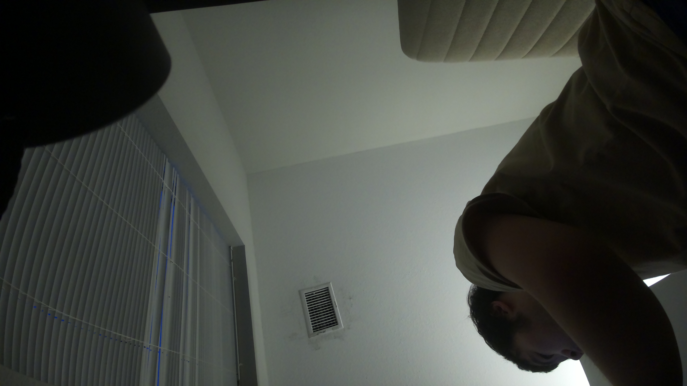
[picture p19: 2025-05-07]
notebook/Liangcheng Sun/test_image_result/autodetect_results_2025_04_15/images/frame_20250415_195153.jpg

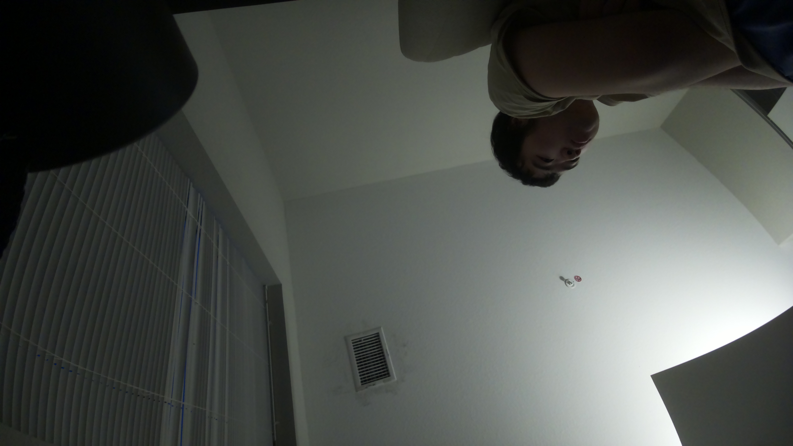
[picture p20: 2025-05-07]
notebook/Liangcheng Sun/test_image_result/autodetect_results_2025_04_15/images/frame_20250415_195414.jpg

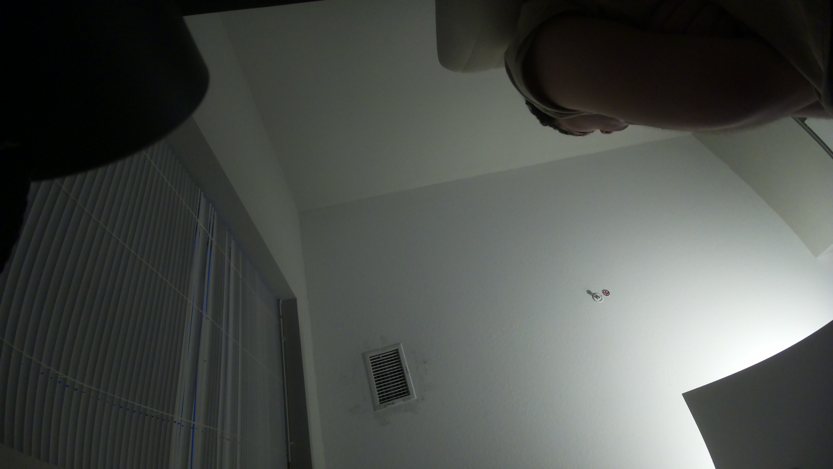
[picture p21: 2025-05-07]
notebook/Liangcheng Sun/test_image_result/autodetect_results_2025_04_15/images/frame_20250415_195346.jpg

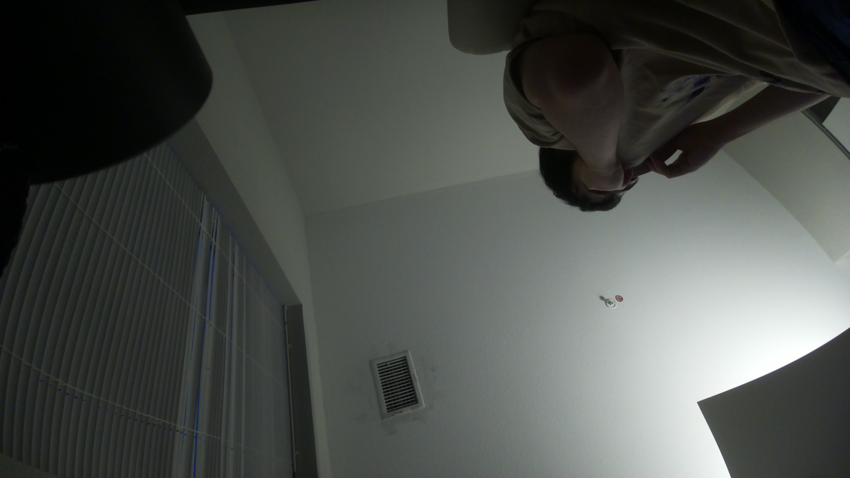
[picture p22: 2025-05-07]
notebook/Liangcheng Sun/test_image_result/autodetect_results_2025_04_15/images/frame_20250415_195250.jpg

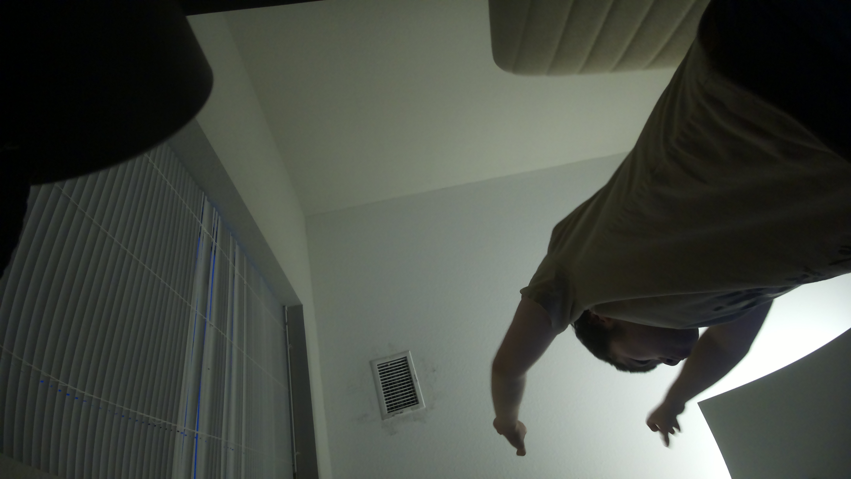
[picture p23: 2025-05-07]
notebook/Liangcheng Sun/test_image_result/autodetect_results_2025_04_15/images/frame_20250415_195222.jpg

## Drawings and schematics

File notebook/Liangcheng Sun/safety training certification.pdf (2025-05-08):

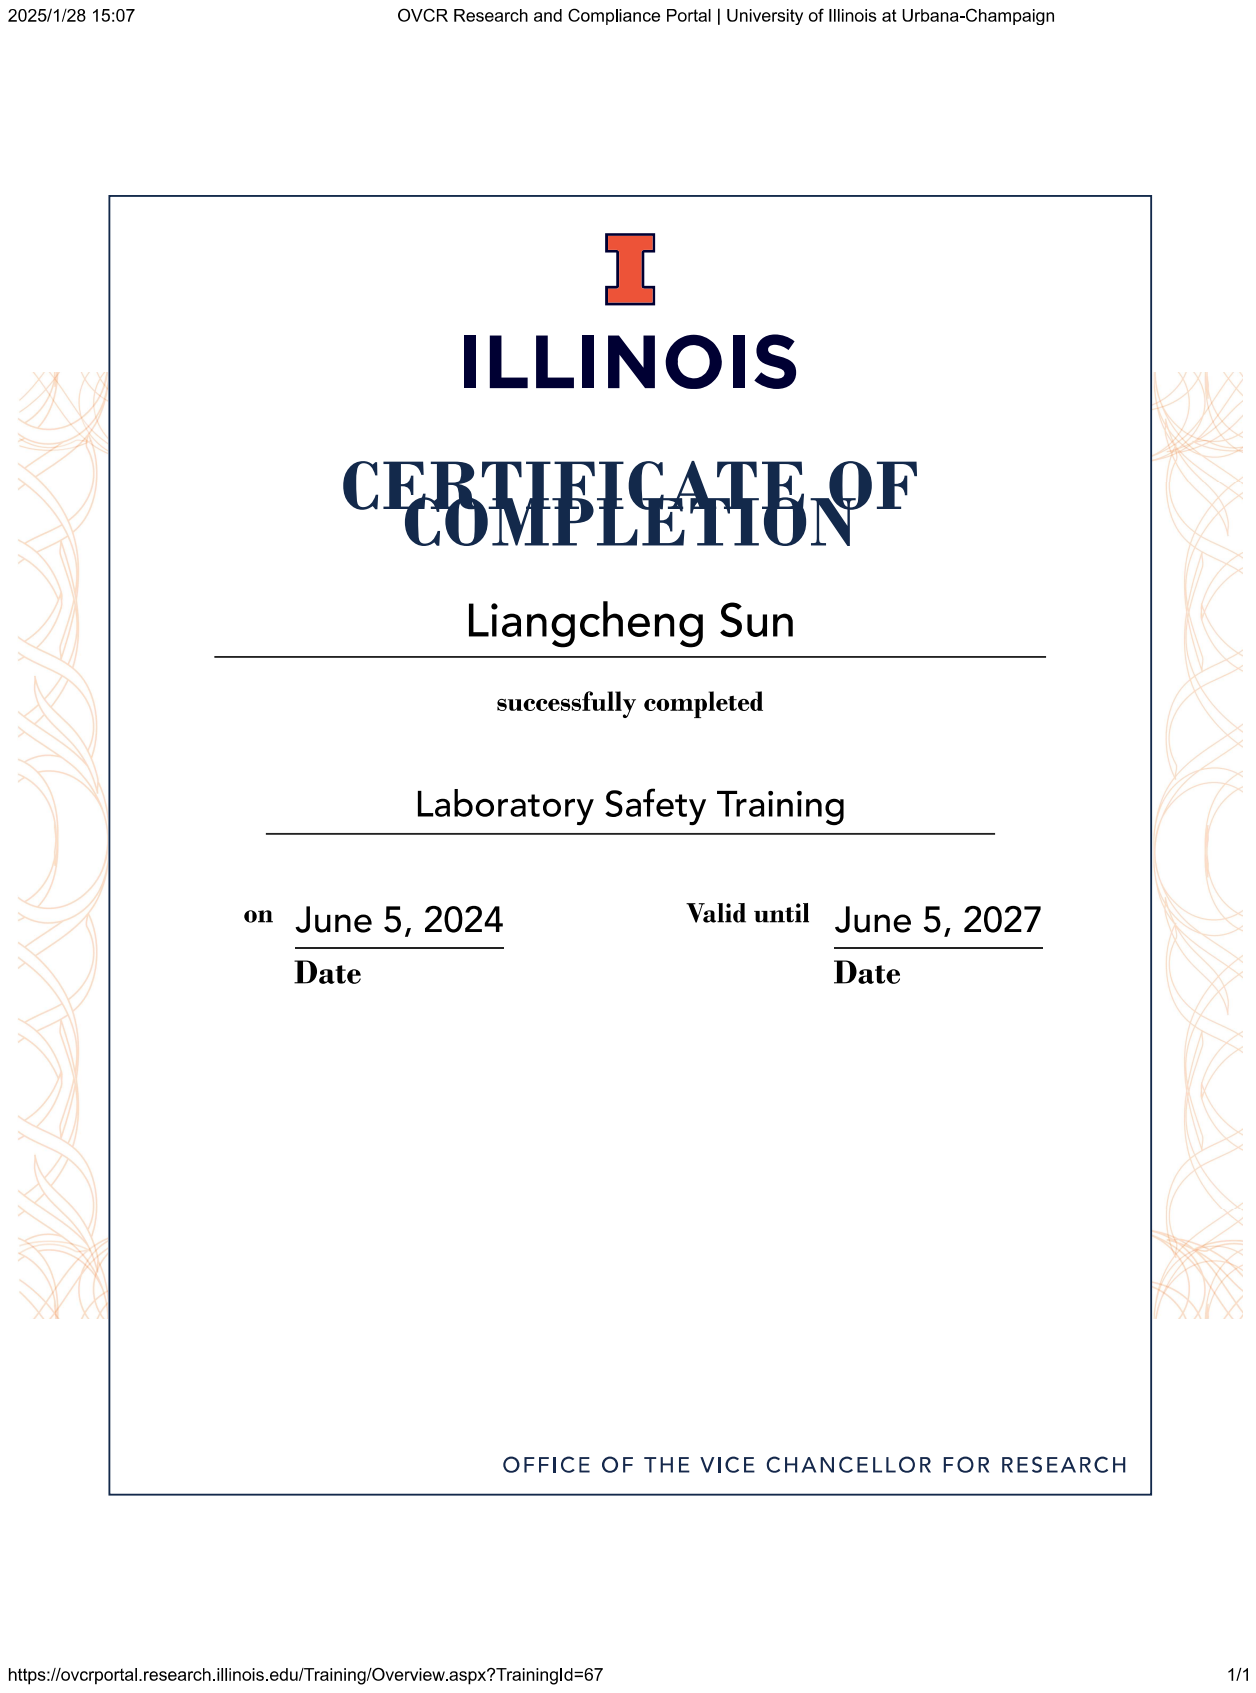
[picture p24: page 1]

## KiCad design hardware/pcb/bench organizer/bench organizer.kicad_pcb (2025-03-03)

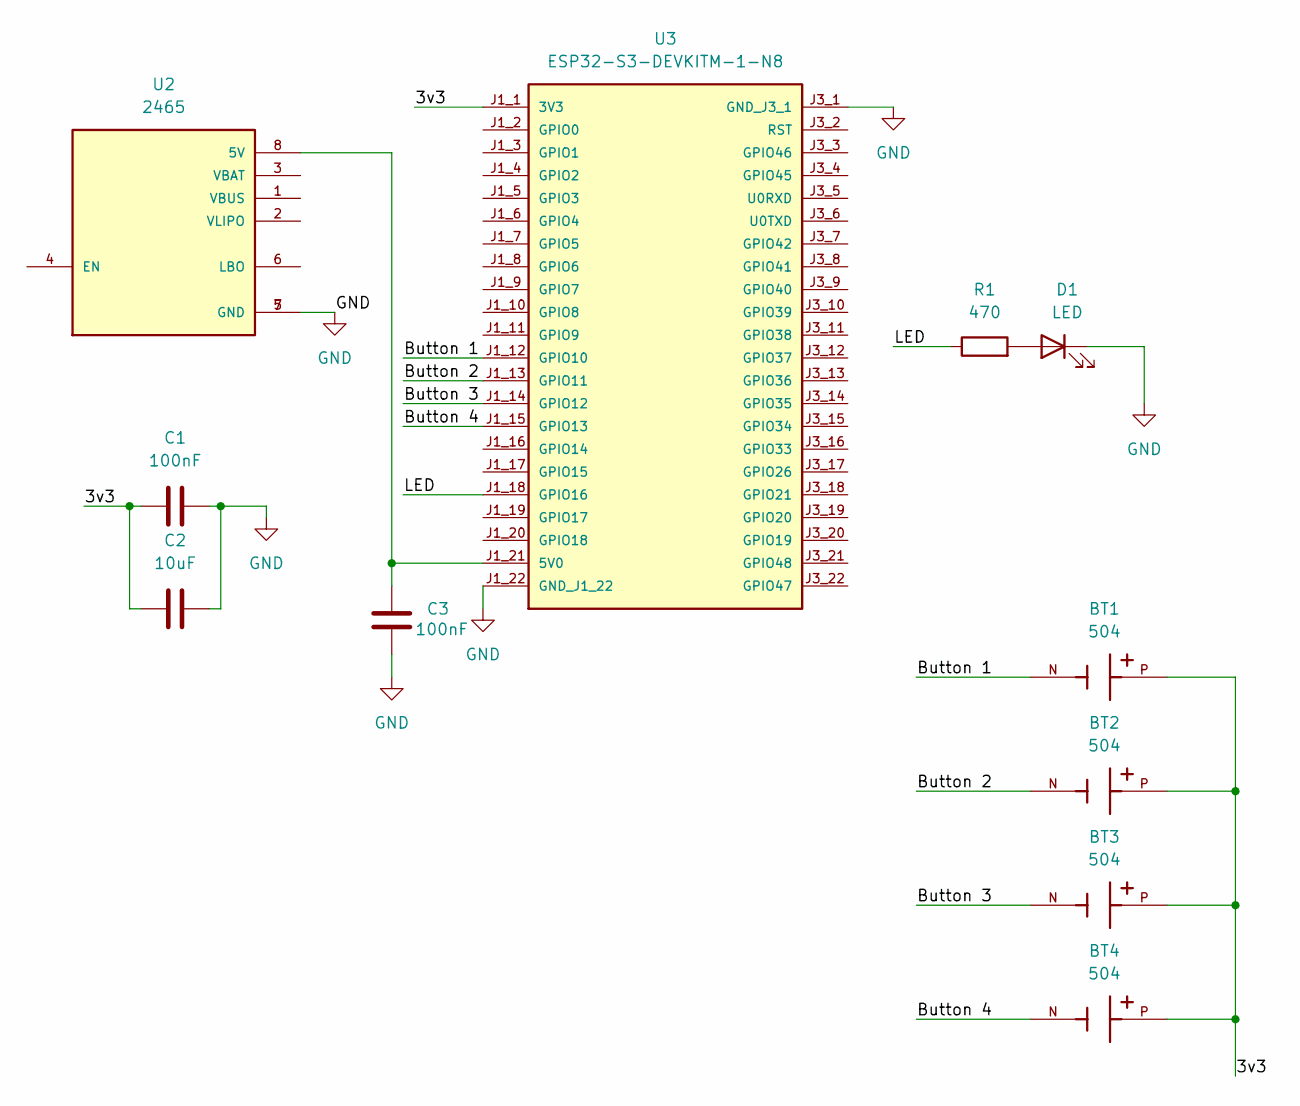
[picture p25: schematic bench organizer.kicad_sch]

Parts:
BT1, BT2, BT3, BT4: 504; BAT_504; PARTREV H
C1, C3: 100nF; CP_Radial_D5.0mm_P2.50mm
C2: 10uF; CP_Radial_D5.0mm_P2.50mm
D1: LED; LED_D5.0mm
R1: 470; R_Axial_DIN0207_L6.3mm_D2.5mm_P7.62mm_Horizontal
U2: 2465; MODULE_2465; PARTREV B
U3: ESP32-S3-DEVKITM-1-N8; MODULE_ESP32-S3-DEVKITM-1-N8; PARTREV 1.0

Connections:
/3v3: BT1.P, BT2.P, BT3.P, BT4.P, C1.1, C2.1, U3.J1_1 (3V3)
/Button 1: BT1.N, U3.J1_12 (GPIO10)
/Button 2: BT2.N, U3.J1_13 (GPIO11)
/Button 3: BT3.N, U3.J1_14 (GPIO12)
/Button 4: BT4.N, U3.J1_15 (GPIO13)
/LED: R1.1, U3.J1_18 (GPIO16)
GND: C1.2, C2.2, C3.2, D1.1 (K), U2.5 (GND), U2.7 (GND), U3.J1_22 (GND_J1_22), U3.J3_1 (GND_J3_1)
unnamed: D1.2 (A), R1.2
unnamed: C3.1, U2.8 (5V), U3.J1_21 (5V0)

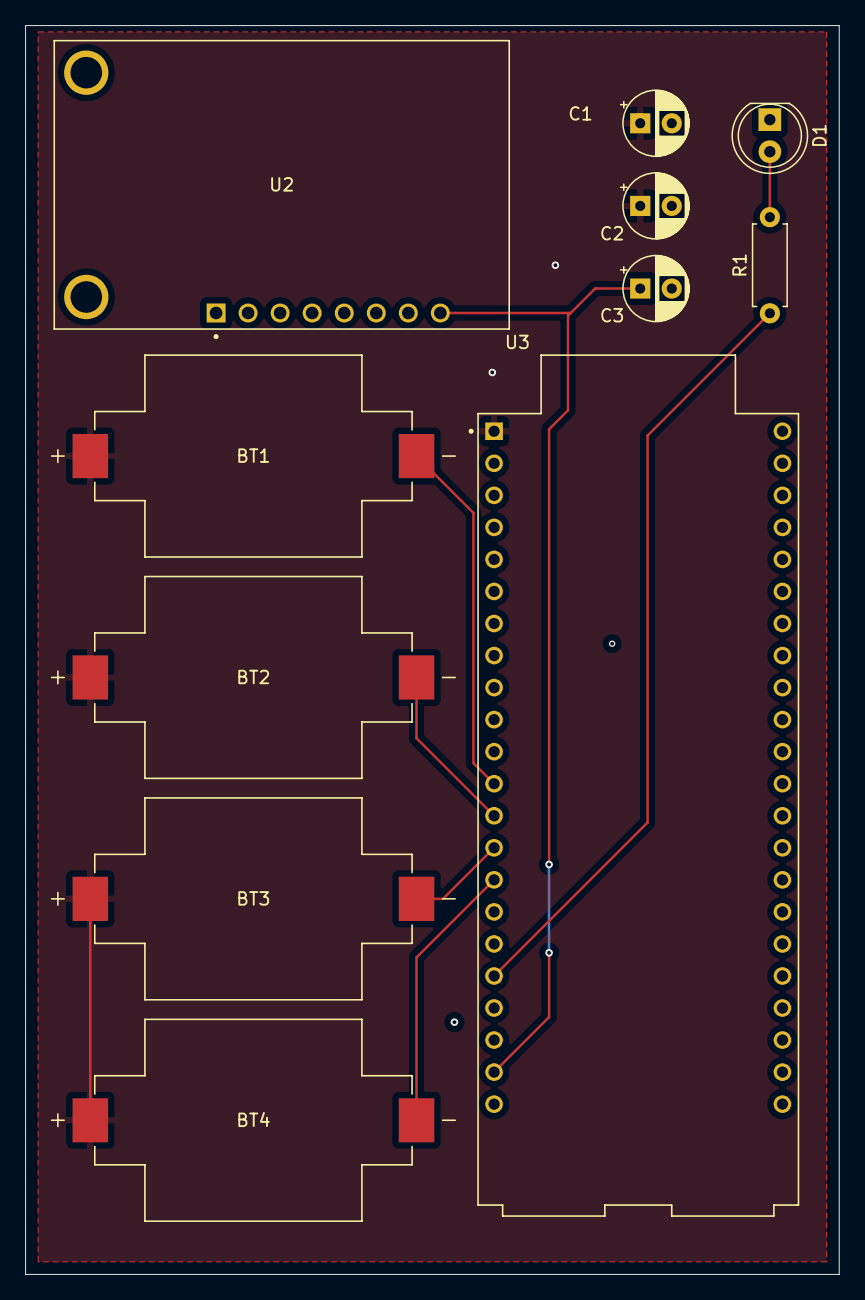
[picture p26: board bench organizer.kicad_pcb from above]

Board: 2 copper layers, 64.5 x 99.0 mm, 11 parts (0 on the bottom side), 9 nets.

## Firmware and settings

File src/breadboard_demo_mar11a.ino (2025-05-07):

#define LED_PIN 11  // Try 2 or 13 if you're unsure

void setup() {
  pinMode(LED_PIN, OUTPUT);
}

void loop() {
  digitalWrite(LED_PIN, HIGH);  // Turn LED on
  delay(500);                   // Wait half a second
  digitalWrite(LED_PIN, LOW);   // Turn LED off
  delay(500);                   // Wait half a second
}

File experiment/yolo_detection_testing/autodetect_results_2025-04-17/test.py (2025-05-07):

#!/usr/bin/env python3
import sys
import time
import serial
import serial.tools.list_ports

def list_ports():
    ports = serial.tools.list_ports.comports()
    for i, p in enumerate(ports):
        print(f"[{i}] {p.device} — {p.description}")
    return ports

def select_port(ports):
    idx = input("Select port number: ")
    try:
        return ports[int(idx)].device
    except:
        print("Invalid selection.")
        sys.exit(1)

def main():
    print("Scanning serial ports...")
    ports = list_ports()
    if not ports:
        print("No serial ports found. Plug in your Nano and try again.")
        return

    port = select_port(ports)
    print(f"Opening {port} @ 115200 baud…")
    try:
        ser = serial.Serial(port, 115200, timeout=1)
    except serial.SerialException as e:
        print("Failed to open serial port:", e)
        return

    time.sleep(2)  # allow Nano to reset
    print("Nano should say “Nano ready” now.")
    line = ser.readline().decode(errors='ignore').strip()
    if line:
        print("→", line)

    def send(cmd, wait=0.5):
        ser.write(cmd.encode())
        time.sleep(wait)
        resp = ser.readline().decode(errors='ignore').strip()
        print(f"Sent '{cmd}', Nano replied:", resp)

    print("\nTesting LED:")
    send('L')   # LED on
    time.sleep(1)
    send('l')   # LED off

    print("\nTesting Buzzer:")
    send('B')   # buzzer on
    time.sleep(1)
    send('b')   # buzzer off

    ser.close()
    print("\nDone.")

if __name__ == "__main__":
    main()

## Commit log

2025-05-07 old design/schematic(no longer used)
2025-05-07 pcb design/schematic
2025-05-07 extra cost
    [Second_Order_Cost_Sheet.csv]
